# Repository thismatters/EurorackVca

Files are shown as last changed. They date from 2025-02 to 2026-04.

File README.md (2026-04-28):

# Voltage Controlled Amplifier

A Voltage Controlled Amplifier amplifies an audio signal based on the voltage control signal. Can be used to shape the incoming audio to an envelope or apply tremolo (envelope not included :).

The circuit here is based on the [Yusynth VCA](https://yusynth.net/Modular/EN/VCA/index.html) with minor tweaks to make it more Eurorack friendly. The changes I've made are thus:
* Selected resistors appropriate for +/-12V rails,
* Added polarity protection so that a backward power header doesn't fry anything (twin series schotty diodes: BAT54SL),
* Selected a modern dual NPN diode package for matched transistors,
* Full surface mount design.

The Yusynth page is a treasure trove of information about this circuit that I am too amateur to claim as my own; please read that outstanding page before using this circuit. The page provides many details and other implementations of this circuit that you may find suitable.

The KiCAD project here uses the library/footprints [found in my companion repo](https://github.com/thismatters/EurorackKiCAD).

## Width

6hp on a standard 3U rack.

## Inputs

Twin control voltage inputs, the left input (marked `cv 1`) is attenuated by the `control lvl` knob.
Likewise there are two audio signal inputs, the left of these (marked `in 1`) is attenuated by the `input lvl` knob. An LED near the `input lvl` knob indicates the level of the audio input signal.
The `gain` knob overrides both CV inputs to amplify the input.

## Outputs

Twin outputs. Audio signal.

## Fiddly bits

This module can be _either_ AC or DC coupled.
For the AC coupled version build the circuit as documented.

When assembling, be sure to trim your trimmer legs pretty short lest they short on the body of the potentiometer.

### DC Coupled Version

For the DC coupled version omit the capacitors C1 and C2; short the two pins with wire (you still totally need C3 and C4 though for power regulation!).
Also use linear taper potentiometers for RV1, RV2, and RV3 (still 100kOhm) (Tayda part number `A-2963`).

## Adjustment

You'll need a dual trace oscilloscope a digital volt meter and function generator.

### Input (Cl)amping

1. Turn the `input lvl` knob to maximum (fully clockwise).
1. Turn the `gain` knob to maximum (fully clockwise).
1. Connect your function generator to the leftmost audio input (marked `in 1`) and to one of the oscilloscope channels.
1. Set up your function generator to give a 1kHz sine at 4 volts (peak to peak).
1. Connect the other oscilloscope channel to one of the outputs.
1. Adjust RV4 until the two oscilloscope traces match exactly. (If your output has flat peaks or troughs then a little tweak to RV6 will smooth those out)
1. Turn the `gain` knob to minimum (fully counterclockwise, there must also be no control voltage plugged in).
1. Adjust RV6 until there is no signal output which appears on the oscilloscope.

### DC Offset

1. Disconnect all inputs.
1. Turn all knobs to minimum (fully counterclockwise).
1. Connect your voltmeter to TP1.
1. Adjust RV5 until the voltmeter reads 0V.

## Vendors

There are part numbers in the [BOM](vca.csv) for many of the parts (not for basic passives though) at the following vendors:

* [Mouser](https://www.mouser.com): Needs no introduction. Get your ICs from here (or [digikey](https://www.digikey.com)).
* [Tayda Electronics](https://www.taydaelectronics.com/): Good supplier for passive components; audio jacks, and potentiometers. Their audio jacks are slightly smaller than the thonkiconn from thonk.
* [Love My Switches](https://lovemyswitches.com/): Has [really good knobs](https://lovemyswitches.com/anodized-aluminum-knob-the-lo-fi-1-4-smooth-shaft-12-5mm-od/) to go on those potentiometers!
* [OSHPark](https://oshpark.com/): Fast and (relatively) cheap PCB manufacturer. The [V1 circuit](https://oshpark.com/shared_projects/VmwAFYtq) works well.

## Changelog

### V2a

- [x] Updated to use correct SMD discrete transistors footprint :facepalm:

### V2

- [x] Switched to NPN for driving LED
- [x] Updated design language (redid board layout too!)
- [x] Switched to SMD discrete transistors
- [x] Corrected BOM issues

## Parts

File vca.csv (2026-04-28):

# | Reference | Qty | Value | Footprint | DNP | Vendor | PartNum | Note
1 | C1, C2 | 2 | 10u 35V BP | Capacitor_THT:CP_Radial_D5.0mm_P2.50mm |  |  |  | Omit and bridge pads for DC version
2 | C3, C4 | 2 | 22u 50V | Capacitor_THT:CP_Radial_D5.0mm_P2.50mm
3 | C5, C6 | 2 | 100n | Capacitor_SMD:C_0805_2012Metric
4 | D1, D2 | 2 | BAT54SL | Package_TO_SOT_SMD:SOT-23 |  | Mouser | 863-BAT54SLT1G
5 | D3 | 1 | LED_GREEN | LED_THT:LED_D3.0mm
6 | J1 | 1 | Signal 1 | eurorack:AudioJack2_Tayda_A-2566 |  | Tayda | A-2566
7 | J2 | 1 | Signal 2 | eurorack:AudioJack2_Tayda_A-2566 |  | Tayda | A-2566
8 | J3 | 1 | CV 1 | eurorack:AudioJack2_Tayda_A-2566 |  | Tayda | A-2566
9 | J4 | 1 | CV 2 | eurorack:AudioJack2_Tayda_A-2566 |  | Tayda | A-2566
10 | J5 | 1 | Out 1 | eurorack:AudioJack2_Tayda_A-2566 |  | Tayda | A-2566
11 | J6 | 1 | Out 2 | eurorack:AudioJack2_Tayda_A-2566 |  | Tayda | A-2566
12 | J7 | 1 | Conn_02x05_Odd_Even | eurorack:PinHeader_2x05_P2.54mm_Vertical |  | Tayda | A-2939
13 | Q1 | 1 | BCM847 | Package_SO:TSOP-6_1.65x3.05mm_P0.95mm |  | Mouser | 771-BCM847DS135
14 | Q2, Q3 | 2 | BC847C | Package_TO_SOT_SMD:SOT-23 |  | Mouser | 621-BC847C-13-F
15 | R1, R2, R3, R4, R10, R11, R14, R17, R22, R25 | 10 | 100K | Resistor_SMD:R_0805_2012Metric
16 | R5, R26 | 2 | 1K | Resistor_SMD:R_0805_2012Metric
17 | R6, R7, R20 | 3 | 15K | Resistor_SMD:R_0805_2012Metric
18 | R8, R9 | 2 | 10K | Resistor_SMD:R_0805_2012Metric
19 | R12 | 1 | 470K | Resistor_SMD:R_0805_2012Metric
20 | R13 | 1 | 470 | Resistor_SMD:R_0805_2012Metric
21 | R15, R16 | 2 | 68K | Resistor_SMD:R_0805_2012Metric
22 | R18, R19 | 2 | 22K | Resistor_SMD:R_0805_2012Metric
23 | R21 | 1 | 33K | Resistor_SMD:R_0805_2012Metric
24 | R23, R24 | 2 | 10 | Resistor_SMD:R_0805_2012Metric
25 | RV1, RV2, RV3 | 3 | A100K | eurorack:Potentiometer_RV16AF-41-15R1 |  | Tayda | A-5407 | Use B100K for DC version
26 | RV4 | 1 | 1K | Potentiometer_THT:Potentiometer_Bourns_3296W_Vertical |  | Tayda | A-585
27 | RV5 | 1 | 100K | Potentiometer_THT:Potentiometer_Bourns_3296W_Vertical |  | Tayda | A-587
28 | RV6 | 1 | 47K | Potentiometer_THT:Potentiometer_Bourns_3296W_Vertical |  | Tayda | A-598
29 | U1 | 1 | TL074 | Package_SO:SOIC-14_3.9x8.7mm_P1.27mm |  | Mouser | 595-TL074CDR

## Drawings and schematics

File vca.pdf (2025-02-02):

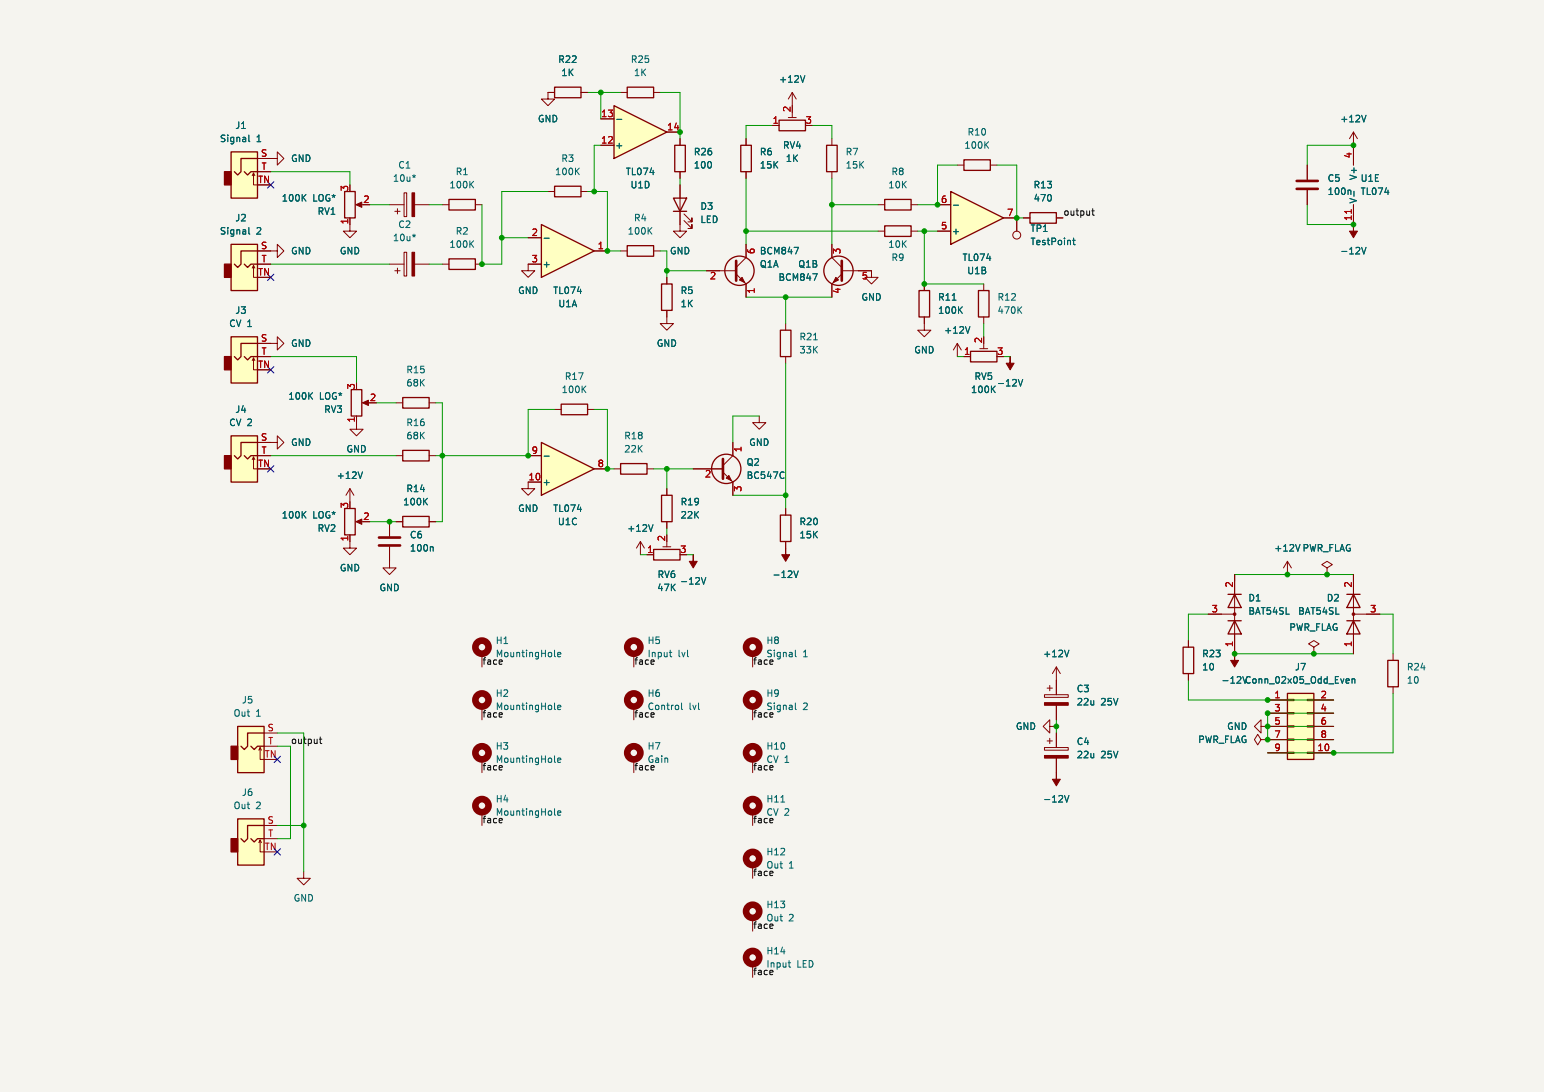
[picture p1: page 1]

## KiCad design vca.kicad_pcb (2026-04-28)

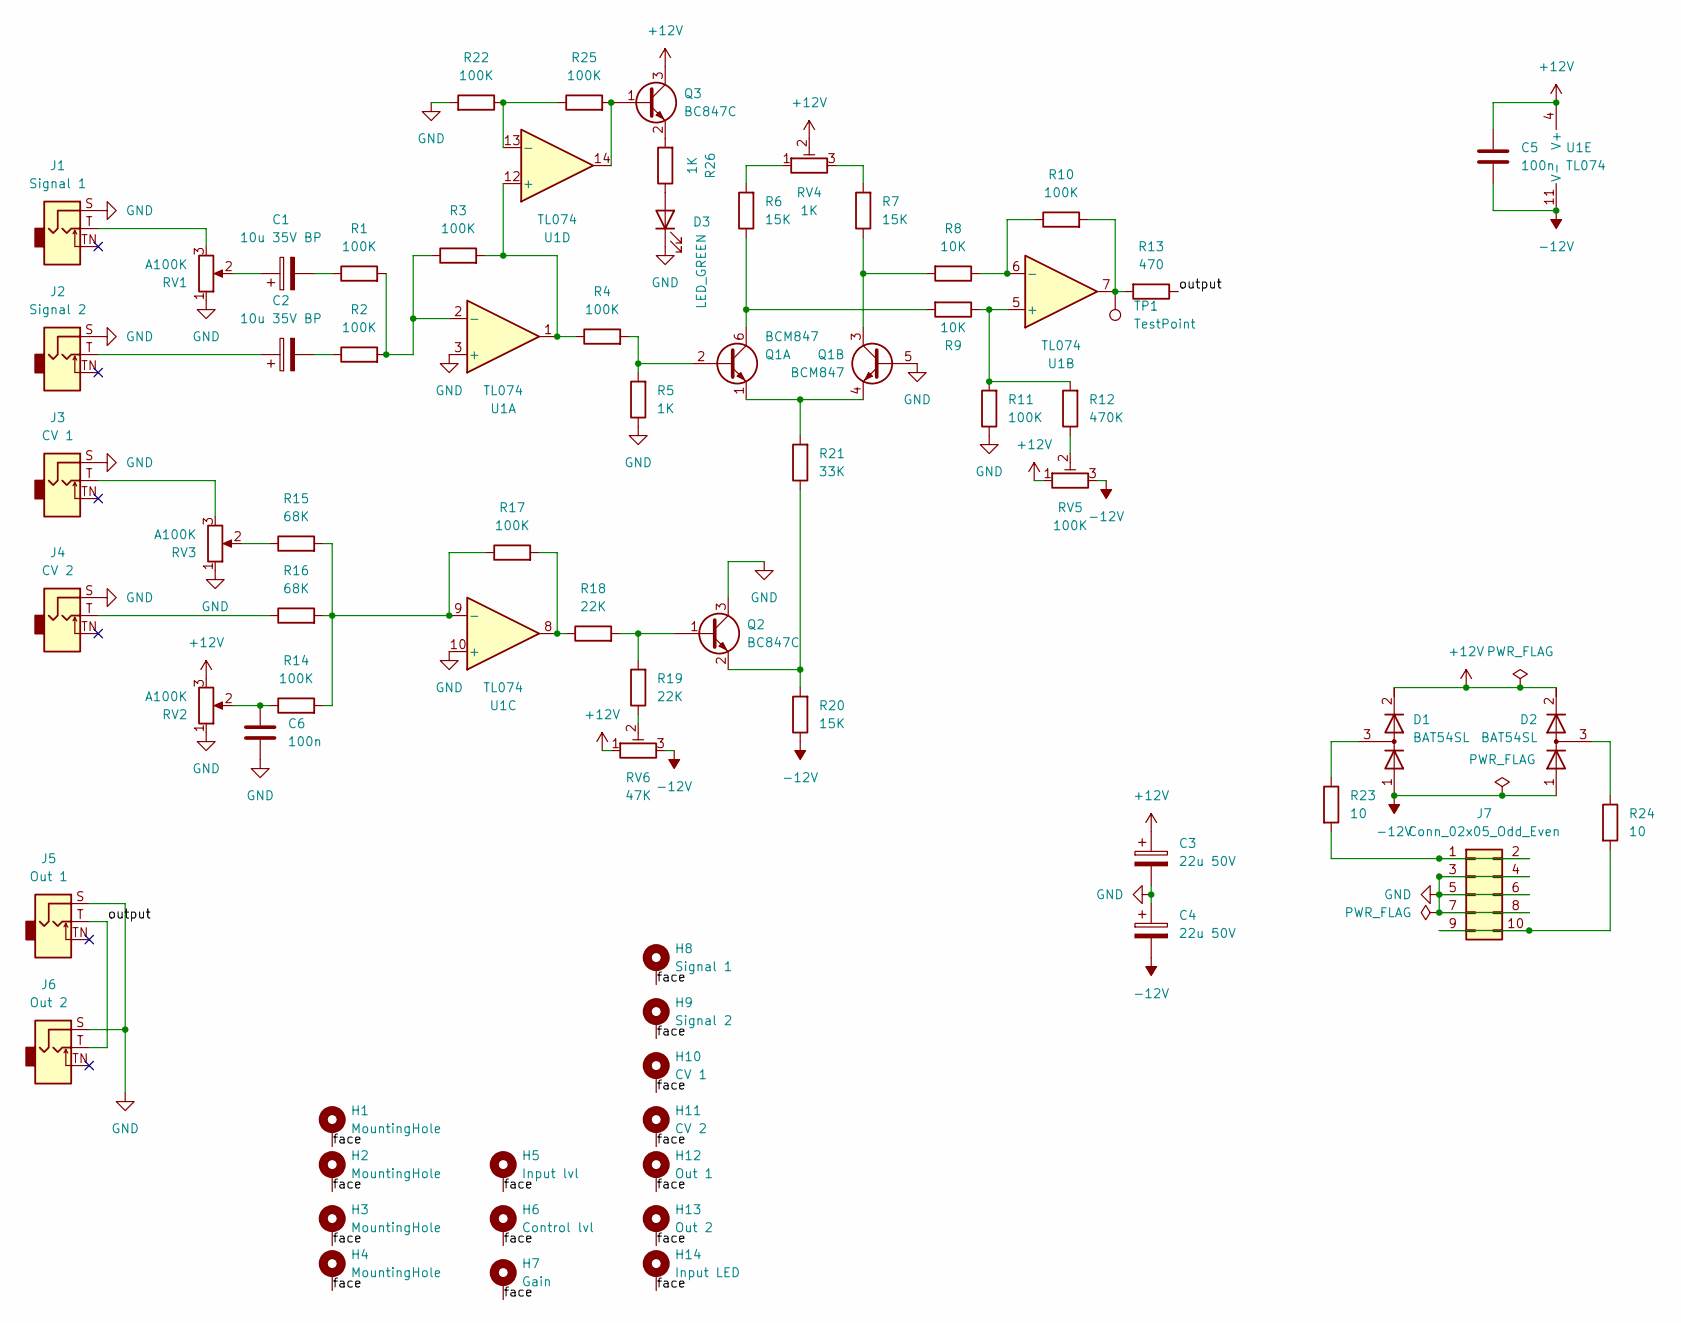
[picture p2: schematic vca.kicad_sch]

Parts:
C1, C2: 10u 35V BP; CP_Radial_D5.0mm_P2.50mm
C3, C4: 22u 50V; CP_Radial_D5.0mm_P2.50mm
C5, C6: 100n; C_0805_2012Metric
D1, D2: BAT54SL; SOT-23; PartNum 863-BAT54SLT1G
D3: LED_GREEN; LED_D3.0mm
H1, H2, H3, H4: MountingHole; Mech-MountingHole
H5: Input lvl; Mech-Potentiometer-Hole_level
H6: Control lvl; Mech-Potentiometer-Hole_level
H7: Gain; Mech-Potentiometer-Hole_level
H8: Signal 1; Mech-AudioJack-Hole-Input
H9: Signal 2; Mech-AudioJack-Hole-Input
H10: CV 1; Mech-AudioJack-Hole-Input-CV
H11: CV 2; Mech-AudioJack-Hole-Input-CV
H12: Out 1; Mech-AudioJack-Hole-Output
H13: Out 2; Mech-AudioJack-Hole-Output
H14: Input LED; Mech-LED-Hole-3mm-Bezel
J1: Signal 1; AudioJack2_Tayda_A-2566; PartNum A-2566
J2: Signal 2; AudioJack2_Tayda_A-2566; PartNum A-2566
J3: CV 1; AudioJack2_Tayda_A-2566; PartNum A-2566
J4: CV 2; AudioJack2_Tayda_A-2566; PartNum A-2566
J5: Out 1; AudioJack2_Tayda_A-2566; PartNum A-2566
J6: Out 2; AudioJack2_Tayda_A-2566; PartNum A-2566
J7: Conn_02x05_Odd_Even; PinHeader_2x05_P2.54mm_Vertical; PartNum A-2939
Q1: BCM847; TSOP-6_1.65x3.05mm_P0.95mm; PartNum 771-BCM847DS135
Q2, Q3: BC847C; SOT-23; PartNum 621-BC847C-13-F
R1, R2, R3, R4, R10, R11, R14, R17, R22, R25: 100K; R_0805_2012Metric
R5, R26: 1K; R_0805_2012Metric
R6, R7, R20: 15K; R_0805_2012Metric
R8, R9: 10K; R_0805_2012Metric
R12: 470K; R_0805_2012Metric
R13: 470; R_0805_2012Metric
R15, R16: 68K; R_0805_2012Metric
R18, R19: 22K; R_0805_2012Metric
R21: 33K; R_0805_2012Metric
R23, R24: 10; R_0805_2012Metric
RV1, RV2, RV3: A100K; Potentiometer_RV16AF-41-15R1; PartNum A-5407
RV4: 1K; Potentiometer_Bourns_3296W_Vertical; PartNum A-585
RV5: 100K; Potentiometer_Bourns_3296W_Vertical; PartNum A-587
RV6: 47K; Potentiometer_Bourns_3296W_Vertical; PartNum A-598
TP1: TestPoint; TestPoint_Plated_Hole_D2.0mm; PartNum 595-TL074CDR
U1: TL074; SOIC-14_3.9x8.7mm_P1.27mm; PartNum 595-TL074CDR

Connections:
+12V: C3.1, C5.1, D1.2 (K), D2.2 (K), Q3.3 (C), RV2.3, RV4.2, RV5.1, RV6.1, U1.4 (V+)
-12V: C4.2, C5.2, D1.1 (A), D2.1 (A), R20.1, RV5.3, RV6.3, U1.11 (V-)
/face: H1.1, H2.1, H3.1, H4.1, H5.1, H6.1, H7.1, H8.1, H9.1, H10.1, H11.1, H12.1, H13.1, H14.1
/output: J5.T, J6.T, R13.1
GND: C3.2, C4.1, C6.2, D3.1 (K), J1.S, J2.S, J3.S, J4.S, J5.S, J6.S, J7.3, J7.4, J7.5, J7.6, J7.7, J7.8, Q1.5 (B2), Q2.3 (C), R5.1, R11.1, R22.2, RV1.1, RV2.1, RV3.1, U1.3 (+), U1.10 (+)
unnamed: C1.1, RV1.2
unnamed: C1.2, R1.1
unnamed: C2.1, J2.T
unnamed: C2.2, R2.1
unnamed: C6.1, R14.1, RV2.2
unnamed: D1.3 (common), R23.1
unnamed: D2.3 (common), R24.1
unnamed: D3.2 (A), R26.1
unnamed: J1.T, RV1.3
unnamed: J3.T, RV3.3
unnamed: J4.T, R16.1
unnamed: J7.1, J7.2, R23.2
unnamed: J7.9, J7.10, R24.2
unnamed: Q1.2 (B1), R4.2, R5.2
unnamed: Q1.6 (C1), R6.1, R9.2
unnamed: Q1.1 (E1), Q1.4 (E2), R21.2
unnamed: Q1.3 (C2), R7.1, R8.2
unnamed: Q2.2 (E), R20.2, R21.1
unnamed: Q2.1 (B), R18.2, R19.2
unnamed: Q3.2 (E), R26.2
unnamed: Q3.1 (B), R25.2, U1.14
unnamed: R6.2, RV4.1
unnamed: R7.2, RV4.3
unnamed: R10.2, R13.2, TP1.1, U1.7
unnamed: R12.1, RV5.2
unnamed: R15.1, RV3.2
unnamed: R17.2, R18.1, U1.8
unnamed: R19.1, RV6.2
unnamed: R1.2, R2.2, R3.1, U1.2 (-)
unnamed: R9.1, R11.2, R12.2, U1.5 (+)
unnamed: R8.1, R10.1, U1.6 (-)
unnamed: R14.2, R15.2, R16.2, R17.1, U1.9 (-)
unnamed: R3.2, R4.1, U1.1, U1.12 (+)
unnamed: R22.1, R25.1, U1.13 (-)

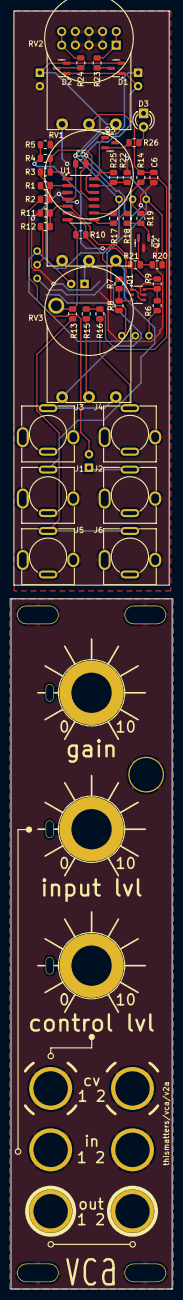
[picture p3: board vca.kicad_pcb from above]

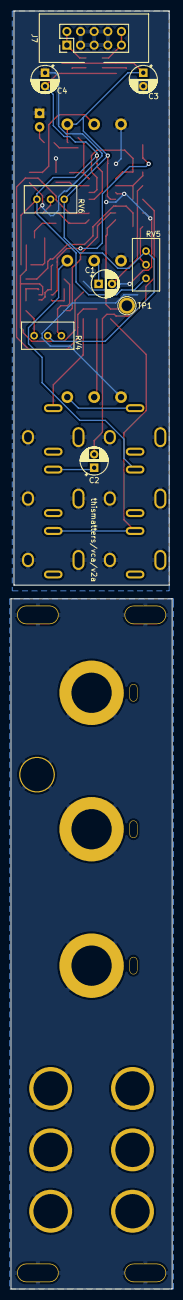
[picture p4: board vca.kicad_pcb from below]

Board: 2 copper layers, 30.0 x 237.9 mm, 67 parts (9 on the bottom side), 39 nets.

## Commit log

2024-01-01 initial commit -- breadboard tested circuit
    [vca.csv, vca.kicad_pcb, vca.kicad_sch]
2024-01-02 prepping for initial manu
    [vca.csv, vca.kicad_pcb, vca.kicad_sch]
2024-01-15 sent to manu
    [vca.kicad_pcb]
2024-11-24 adding pcb link
2025-02-02 add schematic pdf
2025-12-31 v2 ready
    [vca.csv, vca.kicad_pcb, vca.kicad_sch]
2026-01-01 correcting some BOM issues
    [vca.csv, vca.kicad_pcb, vca.kicad_sch]
2026-01-30 v2 actually ready for manu
    [vca.csv, vca.kicad_pcb, vca.kicad_sch]
2026-01-30 one last BOM issue
    [vca.csv, vca.kicad_pcb, vca.kicad_sch]
2026-02-01 use bipolar resistor at input
    [vca.csv, vca.kicad_pcb, vca.kicad_sch]
2026-04-28 bugfixes, update to kicad version 10
    [vca.csv, vca.kicad_pcb, vca.kicad_sch]
